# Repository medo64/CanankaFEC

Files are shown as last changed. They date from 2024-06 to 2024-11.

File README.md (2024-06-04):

[CAN Bus Framework Expansion Card](https://medo64.com/cananka/)
===============================================================

Cananka allows for the computer control of a CAN bus. The control of device is
possible via serial port (SLCAN compatible, Windows/Linux) or via SocketCAN
network driver (Linux).

## CAN Bus Pinout

To connect to this board, one has to use a 4-pin JST XH connector. The following
table represents the pinout, pin 1 being on the left as looking into the
expansion card.

| # | Ref | Description |
|--:|:-----:|---|
| 1 | GND | Ground connection |
| 2 | CAN L | CAN low-side |
| 3 | CAN H | CAN high-side |
| 4 | V+ | Not connected |

As power consumption is low, wires can be almost any AWG. I would recommend
using 24 AWG wire 0.25 mm² as they allow for greater compatibility with other
connectors.

## LEDs

Left LED will blink on UART communication with computer (both sending toward and
receiving data from computer).

Right LED will blink on CAN bus activity.

## Other repositories

The following hardware version are also available:
* [Full](https://github.com/medo64/Cananka) (isolated and in the case)
* [Framework Expansion Card](https://github.com/medo64/CanankaFEC) (non-isolated, in framework expansion card format)
* [HAT](https://github.com/medo64/CanankaHAT) (intended for Raspberry Pi)

The following additional repositories might be of interest:
* [Firmware](https://github.com/medo64/Cananka.Firmware)
* [Protocol](https://github.com/medo64/Cananka.Firmware/blob/main/PROTOCOL.md)
* [Test software](https://github.com/medo64/Cananka.Software)

---
*You can check my blog and other projects at [www.medo64.com](https://www.medo64.com/electronics/).*

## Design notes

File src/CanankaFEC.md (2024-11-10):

### CanankaFEC Parts

|  # | Part | RefDes  | Preferred Part Number |
|---:|---|---|---|
|  1 | C 10nF X7R 16V (0805) | C1 | 399-17617-1-ND |
|  5 | C 100nF X7R 16V (0805) | C2-C6 | 478-5311-1-ND |
|  1 | C 4.7uF X5R 16V (0805) | C7 | 1276-1244-1-ND |
|  1 | C 10uF X5R 16V (0805) | C8 | 1276-1096-1-ND |
|  1 | D TVS 150W Zenner CAN (SOT23-3) | D1 | 497-13262-1-ND  568-4032-1-ND |
|  2 | DS LED (0805) | DS1-DS2 | 475-1415-1-ND |
|  1 | J USB C, plug, straddle 0.8mm | J1 | WM12855-ND |
|  1 | J JST XH Vertical (4w) | J2 | 455-B4B-XH-A-ND |
|  1 | L Ferrite 600R@100Mhz | L1 | 240-2390-1-ND |
|  3 | Q P-MOSFET 50V 120mA BSS84 (SOT23-3) | Q1-Q3 | BSS84CT-ND |
|  2 | R 59 1% 0.25W (0805) | R1-R2 | 2019-RK73H2ATTD59R0FCT-ND |
|  3 | R 1K 0.125W (0805) | R3-R5 | RMCF0805FT1K00CT-ND |
|  2 | R 5.1K 0.125W (0805) | R6-R7 | RMCF0805FT5K10CT-ND |
|  1 | U FT232R (SSOP-28) | U1 | 768-FT232RNL-TUBE-ND |
|  1 | U PIC18F25K80 (SSOP-28) | U2 | PIC18F25K80-I/SS-ND |
|  1 | U MCP2561 (SOIC-8) | U3 | MCP2561-E/SN-ND |
|  2 | H Screw M2x3mm | - | - |

#### Board Size

| | Dimensions | Area | Thickness |
|---|---|---|---|
| PCB |  24.0 x 27.9 mm | 1.1 in² | 0.8 mm |

#### FTDI Configuration

| Setting | Value  |
|---|---|
| CBUS0 | TXLED# |
| CBUS1 | RXLED# |
| CBUS2 | TXDEN  |
| CBUS3 | PWREN# |
| CBUS4 | CLK12  |

#### Power

| Property | Value  |
|---|---:|
| Voltage  | 5 V |
| Current  | 200 mA |

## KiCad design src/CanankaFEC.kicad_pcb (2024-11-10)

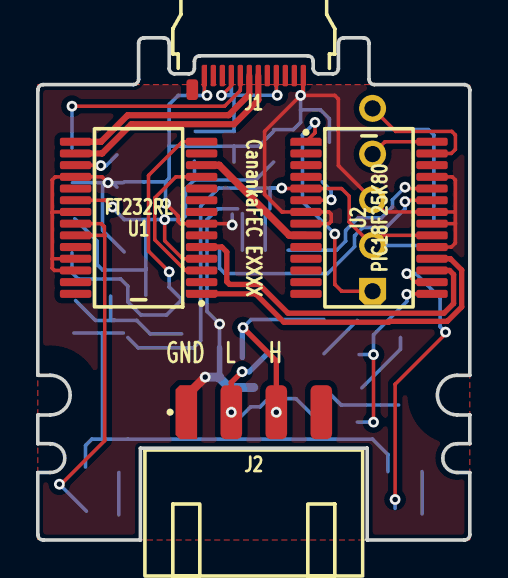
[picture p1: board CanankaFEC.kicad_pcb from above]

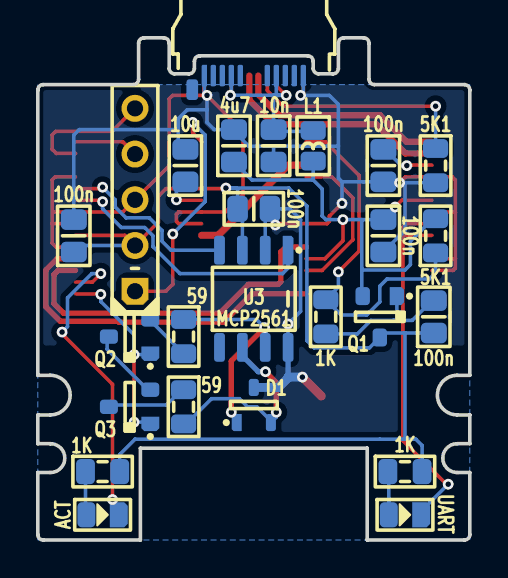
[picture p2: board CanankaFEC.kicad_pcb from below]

Board: 2 copper layers, 24.0 x 27.9 mm, 28 parts (24 on the bottom side), 30 nets.

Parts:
C1: 10n; C (0805)
C2, C3, C4, C5, C6: 100n; C (0805)
C7: 4u7; C (0805)
C8: 10u; C (0805)
D1: TVS; D TVS 24V [PESD24VL2BT,215] (SOT23-3)
DS1: UART; DS (0805)
DS2: ACT; DS (0805)
ICSP: Microchip PIC; ICSP PIC Pogo SS (5w)
J1: 105444-0001; J USB C 3.2 Edge (24w)
J2: B3B-XH-A; J JST XH Edge [CAN] (4w)
L1: 600R; L (0805)
Q1, Q2, Q3: BSS84; Q MOSFET-P (SOT23-3)
R1, R2: 59; R (0805)
R3, R4, R5: 1K; R (0805)
R6, R7: 5K1; R (0805)
U1: FT232RL; U Transceiver UART [FT232R] (SSOP-28)
U2: PIC18F25K80; U Micro [PIC18F25K80] (SSOP-28)
U3: MCP2561; U Transceiver CAN [MCP2561] (SOIC-8)

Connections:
3V3: C3.2, U1.17
5V: C2.2, C7.2, L1.1, Q1.2, R7.1, U1.4, U1.20
5V_SW: C4.2, C5.2, C6.2, ICSP.2, Q1.3, R3.1, R4.1, U2.5, U2.20, U3.3
A_CC: J1.A5, R6.2
CANRX: U2.24, U3.4
CANTX: U2.23, U3.1
CAN_H: D1.1, J2.3, R1.2, U3.7
CAN_H_TERM: Q2.2, R1.1
CAN_I_TERM: Q2.3, Q3.2
CAN_L: D1.2, J2.2, R2.1, U3.6
CAN_L_TERM: Q3.3, R2.2
CLOCK: U1.12, U2.9
GND: C1.1, C2.1, C3.1, C5.1, C6.1, C7.1, C8.1, D1.3, ICSP.3, J1.A1, J1.A12, J1.B01, J1.B12, J2.1, R6.1, U1.7, U1.18, U1.21, U1.25, U1.26, U2.7, U2.8, U2.19, U2.21, U2.22, U2.25, U3.2, U3.8
ICSP_CLK: ICSP.5, U2.27
ICSP_DAT: ICSP.4, U2.28
ICSP_VPP: ICSP.1, U2.1
IO_CONTROL_TERMINATE#: Q2.1, Q3.1, U2.15
LED_ACTIVITY: DS2.1, U2.16
LED_ACTIVITY': DS2.2, R4.2
LED_UART: DS1.1, U1.22, U1.23
LED_UART': DS1.2, R3.2
PWREN#: R5.1, R7.2, U1.14
PWREN#': C4.1, Q1.1, R5.2
RTS_CTS: U1.3, U1.11
RXD: U1.5, U2.17
TXD: U1.1, U2.18
USB_DM: J1.A7, U1.16
USB_DP: J1.A6, U1.15
USB_Vin: C1.2, J1.A4, J1.A9, J1.B04, J1.B09, L1.2
VDD_CORE: C8.2, U2.6

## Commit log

2023-11-13 Moved LEDs to bottom side
    [CanankaFEC.kicad_pcb]
2023-12-26 Added PWREN pullup and moved LED 5V to switched
    [CanankaFEC.kicad_pcb]
2023-12-30 Refactoring copper pour
    [CanankaFEC.kicad_pcb]
2024-01-28 Moved silkscreen
    [CanankaFEC.kicad_pcb]
2024-01-31 Moved TVS to bottom
    [CanankaFEC.kicad_pcb]
2024-02-04 Swapped UART lines
    [CanankaFEC.kicad_pcb]
2024-04-02 Updated connector designators
    [CanankaFEC.kicad_pcb]
2024-06-05 Updated to KiCAD 8
    [CanankaFEC.kicad_pcb]
2024-06-05 Moved termination resistor to bottom
    [CanankaFEC.kicad_pcb]
2024-08-28 Updated diode footprint
    [CanankaFEC.kicad_pcb]
2024-08-28 Added board designator
    [CanankaFEC.kicad_pcb]
2024-08-28 Updated refdes
    [CanankaFEC.kicad_pcb]
2024-08-28 Added transistor models
    [CanankaFEC.kicad_pcb]
2024-09-08 Fixed termination mosfet setup
    [CanankaFEC.kicad_pcb]
2024-09-08 Consolidating resistors a bit
    [CanankaFEC.kicad_pcb]
2024-11-09 Added pin silkscreen
    [CanankaFEC.kicad_pcb]
2024-11-10 Moved D1 refdes
    [CanankaFEC.kicad_pcb]
2024-11-10 Fixed refdes
    [CanankaFEC.kicad_pcb]
